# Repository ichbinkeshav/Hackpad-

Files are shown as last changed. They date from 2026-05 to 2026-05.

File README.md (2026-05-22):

# HACKPAD+
Screenshot (93)<br>
This is a hackpad that is based on Xiao Rp2040 that has 9 Buttons and 2 Rotor encoder . I utilized the 2 buttons of rotor encoder as well. So in total i have 11 Keys and 2 rotor encoder. For Keys i used 3 x 4 Matrix so i just need 7 gpio pins for it and 4 gpios for 2 encoder. So the rotor encoder is used to control volume and brightness and the 11 keys are used for general useful shortcuts like copy ,paste ,delete ,screenshot ,open youtube ,cut ,undo ,redo ,print ,window close and open file explore, I did the Schematic and PCB on KICAD and 3d Design on Fusion. The Code is written in circuit Python and uses KMK.I used the hackclub guide , which really helped me a lot.<br>
##  Bill of Materials (BOM)

**#**
1 x XIAO RP2040<br>
**#**
9 x MX-Style switches <br>
**#**
9 x Blank DSA keycaps<br>
**#**
2 x EC11 Rotary Encoder<br>
**#**
4 x  M3x16mm screws <br>
**#**
4 x  M3x5mx4mm heatset inserts

**Schematic**<br><br>
Screenshot (95)<br><br>
**PCB**<br>
Screenshot (96)<br><br>
<br>
**Case**<br><br>
Screenshot (94)
Screenshot (92)

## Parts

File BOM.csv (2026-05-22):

Item | Price | Source
PCB + CASE | 6.43 | JLCPCB
Shipping - Discount JLCPCB | 1.47 | JLCPCB
rotor encoder | 1.84 | https://www.amazon.in/gp/product/B0888RWNM1/ref=ox_sc_act_title_1?smid=A34QREQHZ8C5B0&psc=1
Mx Style switches | 4.29 | https://www.amazon.in/gp/product/B0GCCQLQBV/ref=ox_sc_act_title_3?smid=A16FKXBMFHBYH0&psc=1
KeyCaps | 4.6 | https://www.amazon.in/gp/product/B0F13YK4D6/ref=ox_sc_act_title_2?smid=AH0KEO6T9U8SH&psc=1
XIAO RP2040 | 11.49 | https://www.amazon.in/gp/product/B0FVF1V3P4/ref=ox_sc_act_title_4?smid=AJ6SIZC8YQDZX&psc=1
Heat set and M3 screws | 3.67 | https://www.amazon.in/gp/product/B0DZFPP9SV/ref=ewc_pr_img_1?smid=A350QSP9XUT5HY&psc=1 https://www.amazon.in/gp/product/B07XBSYNQ4/ref=ewc_pr_img_2?smid=AJ6SIZC8YQDZX&th=1
Total | 33.89

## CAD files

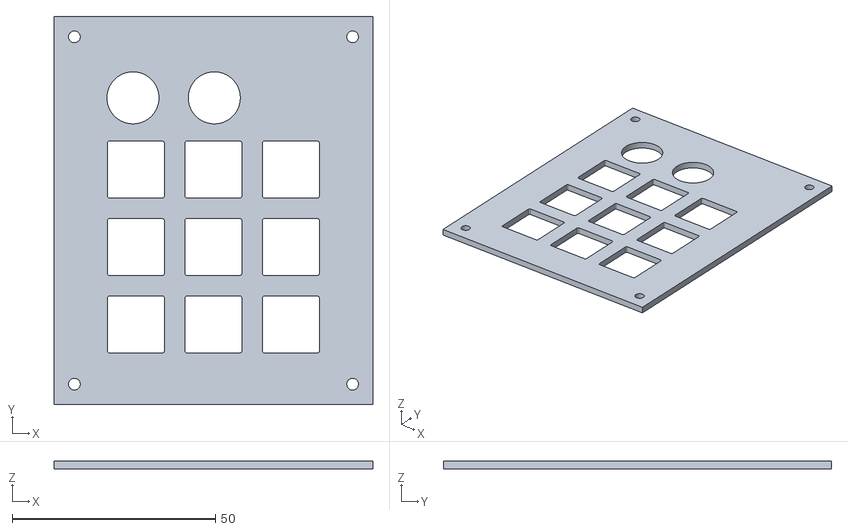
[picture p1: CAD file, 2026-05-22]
HACKPAD+/Production/Top.stl
78.4 x 95.4 x 2.00

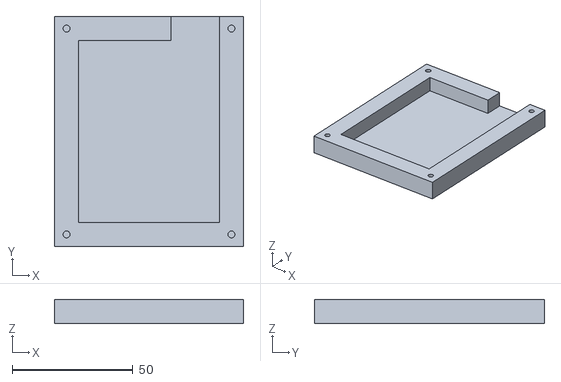
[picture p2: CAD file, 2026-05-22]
HACKPAD+/Production/Base.stl
78.4 x 95.4 x 10.0

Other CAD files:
HACKPAD+/CAD/HACKPAD+.f3d
HACKPAD+/CAD/HACKPAD+.f3z

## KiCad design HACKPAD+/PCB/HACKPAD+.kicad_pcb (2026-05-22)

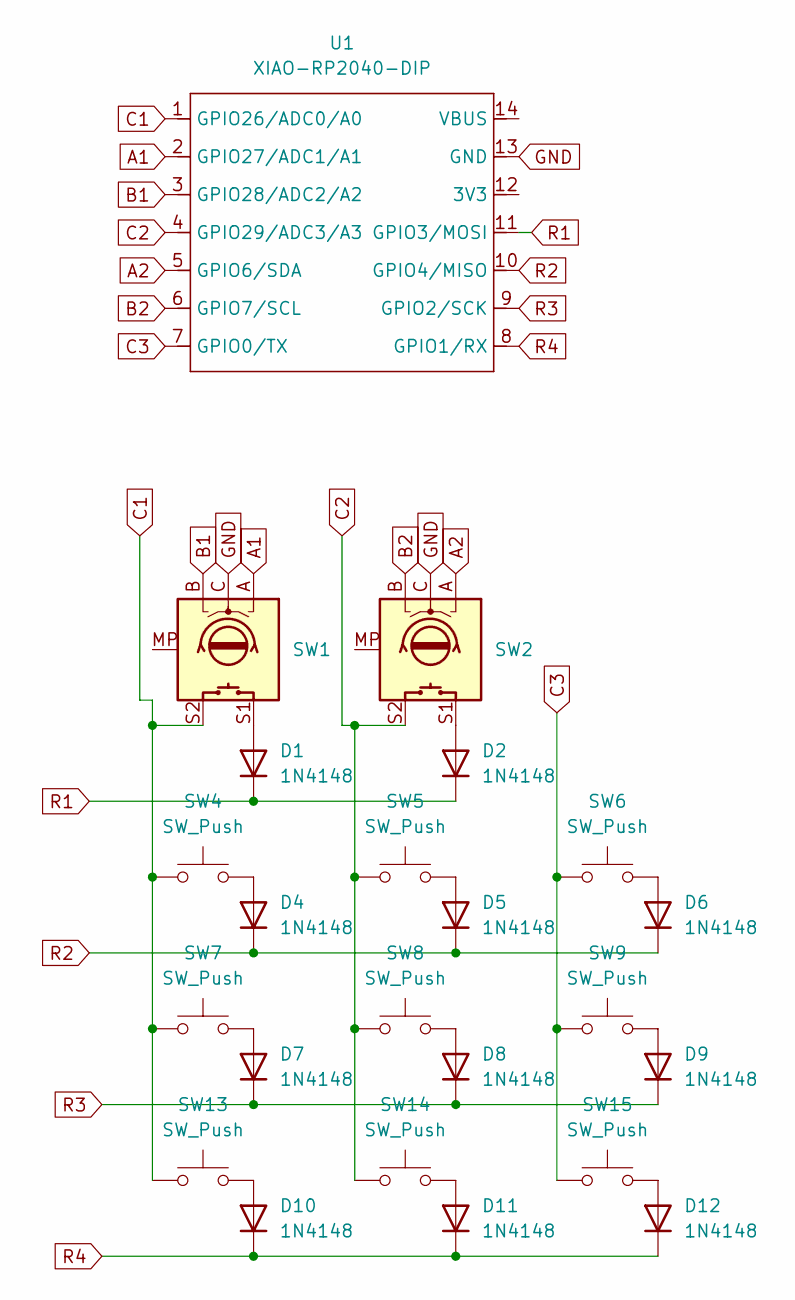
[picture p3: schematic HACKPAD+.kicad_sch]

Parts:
D1, D2, D4, D5, D6, D7, D8, D9, D10, D11, D12: 1N4148; D_DO-35_SOD27_P7.62mm_Horizontal
SW1, SW2: RotaryEncoder_Switch_MP; RotaryEncoder_Alps_EC11E-Switch_Vertical_H20mm
SW4, SW5, SW6, SW7, SW8, SW9, SW13, SW14, SW15: SW_Push; SW_Cherry_MX_1.00u_PCB
U1: XIAO-RP2040-DIP

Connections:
A1: SW1.A, U1.2 (GPIO27/ADC1/A1)
A2: SW2.A, U1.5 (GPIO6/SDA)
B1: SW1.B, U1.3 (GPIO28/ADC2/A2)
B2: SW2.B, U1.6 (GPIO7/SCL)
C1: SW1.S2, SW4.1, SW7.1, SW13.1, U1.1 (GPIO26/ADC0/A0)
C2: SW2.S2, SW5.1, SW8.1, SW14.1, U1.4 (GPIO29/ADC3/A3)
C3: SW6.1, SW9.1, SW15.1, U1.7 (GPIO0/TX)
GND: SW1.C, SW2.C, U1.13 (GND)
unnamed: D1.2 (A), SW1.S1
unnamed: D2.2 (A), SW2.S1
unnamed: D4.2 (A), SW4.2
unnamed: D5.2 (A), SW5.2
unnamed: D6.2 (A), SW6.2
unnamed: D7.2 (A), SW7.2
unnamed: D8.2 (A), SW8.2
unnamed: D9.2 (A), SW9.2
unnamed: D10.2 (A), SW13.2
unnamed: D11.2 (A), SW14.2
unnamed: D12.2 (A), SW15.2
R1: D1.1 (K), D2.1 (K), U1.11 (GPIO3/MOSI)
R2: D4.1 (K), D5.1 (K), D6.1 (K), U1.10 (GPIO4/MISO)
R3: D7.1 (K), D8.1 (K), D9.1 (K), U1.9 (GPIO2/SCK)
R4: D10.1 (K), D11.1 (K), D12.1 (K), U1.8 (GPIO1/RX)

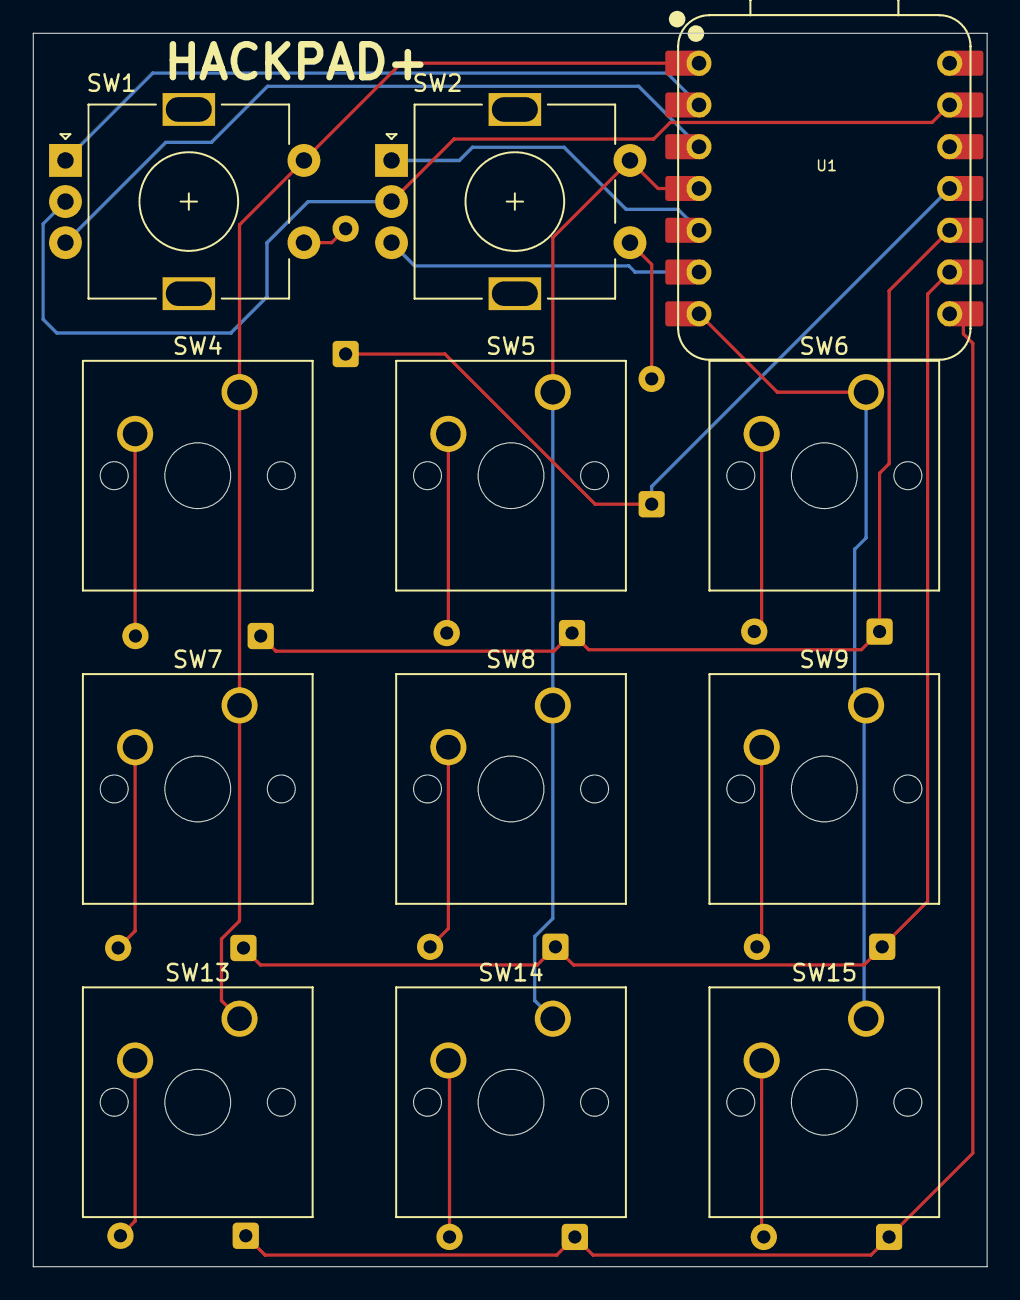
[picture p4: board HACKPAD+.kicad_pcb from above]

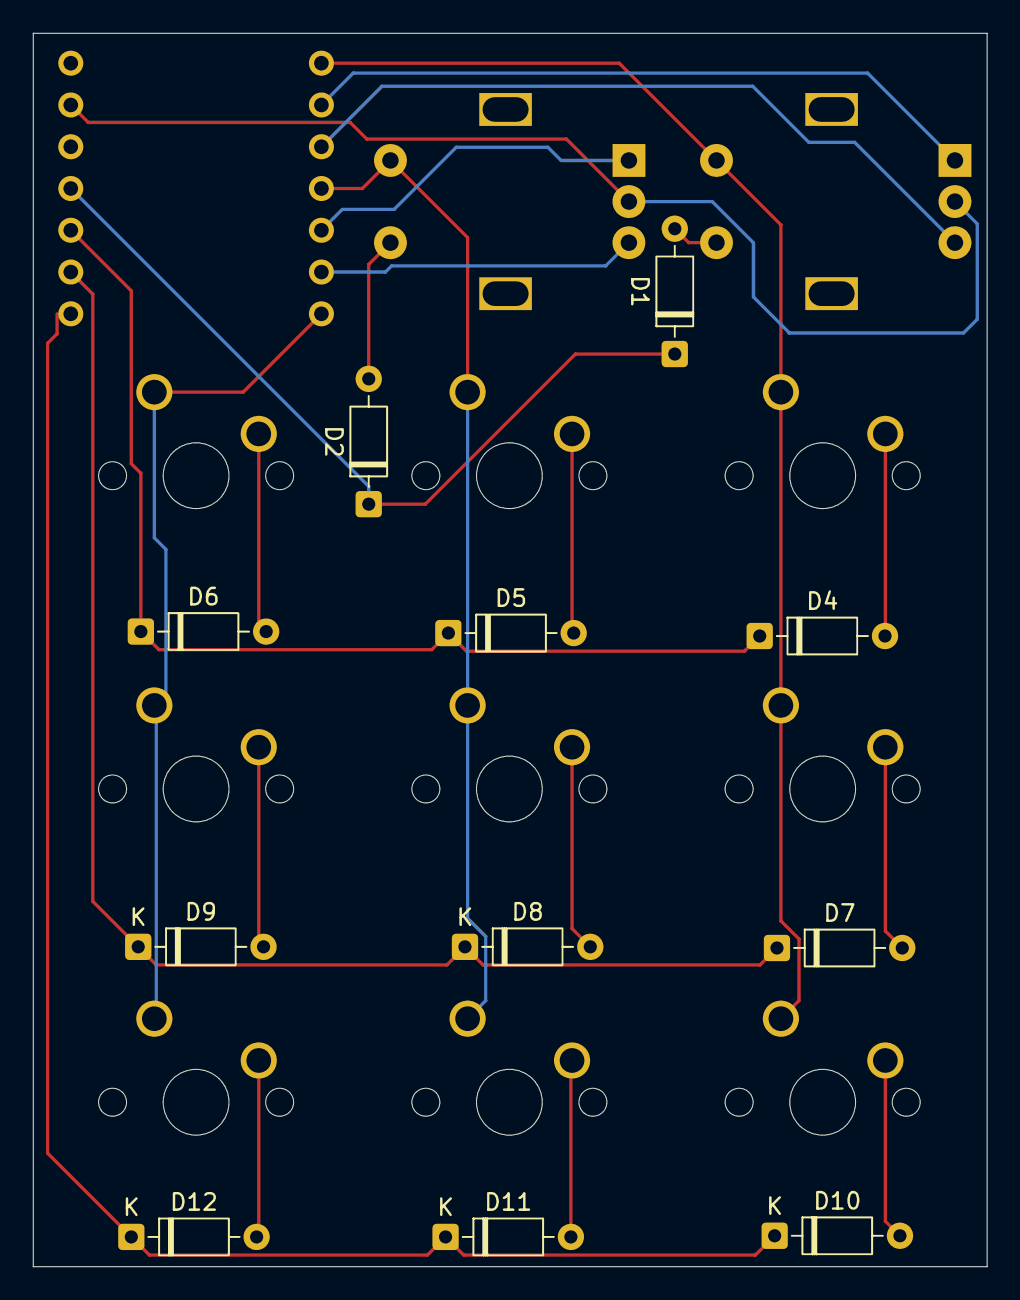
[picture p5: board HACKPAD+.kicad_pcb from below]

Board: 2 copper layers, 58.0 x 75.0 mm, 23 parts (11 on the bottom side), 23 nets.

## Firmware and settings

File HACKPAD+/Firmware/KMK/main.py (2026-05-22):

from kmk.kmk_keyboard import KMKKeyboard
from kmk.keys import KC
from kmk.scanners import DiodeOrientation
from kmk.modules.encoder import EncoderHandler
from kmk.extensions.media_keys import MediaKeys
import board

keyboard = KMKKeyboard()

# ---- MATRIX PINS ----
keyboard.col_pins = (board.GP26, board.GP27, board.GP28)
keyboard.row_pins = (board.GP1, board.GP2, board.GP4, board.GP6)

keyboard.diode_orientation = DiodeOrientation.COL2ROW

# ---- MEDIA EXTENSION ----
keyboard.extensions.append(MediaKeys())

# ---- ENCODERS ----
encoder_handler = EncoderHandler()
keyboard.modules.append(encoder_handler)

# Encoder 1 → Volume
# Encoder 2 → Brightness
encoder_handler.pins = (
    ((board.GP7, board.GP0, None),),   # Encoder 1
    ((board.GP29, board.GP3, None),),  # Encoder 2
)

encoder_handler.map = [
    ((KC.VOLD, KC.VOLU),),   # Encoder 1
    ((KC.BRIGHTNESS_DOWN, KC.BRIGHTNESS_UP),),  # Encoder 2
]

# ---- MACROS ----
YOUTUBE = KC.LGUI(KC.R)  # Windows+R
SCREENSHOT = KC.LGUI(KC.PRINT_SCREEN)

keyboard.keymap = [
    [
        KC.LCTL(KC.C),      # Copy
        KC.LCTL(KC.V),      # Paste
        KC.DELETE,          # Delete

        SCREENSHOT,         # Screenshot
        KC.PRINT_SCREEN,    # Print Screen
        YOUTUBE,            # Open Run (type youtube.com)

        KC.LCTL(KC.X),      # Cut
        KC.LCTL(KC.Z),      # Undo
        KC.LCTL(KC.Y),      # Redo

        KC.LGUI(KC.E),      # File Explorer
        KC.LALT(KC.F4),     # Close Window
        KC.NO               # extra slot
    ]
]

if __name__ == '__main__':
    keyboard.go()

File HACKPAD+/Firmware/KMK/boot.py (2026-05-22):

import board
import digitalio
import storage
import usb_cdc
import usb_hid
import time

# ---- MATRIX PINS ----
cols = [board.GP26, board.GP27, board.GP28]  # C1 C2 C3
rows = [board.GP1, board.GP2, board.GP4, board.GP6]  # R1 R2 R3 R4

# Setup columns as input pullups
col_ios = []
for pin in cols:
    col = digitalio.DigitalInOut(pin)
    col.direction = digitalio.Direction.INPUT
    col.pull = digitalio.Pull.UP
    col_ios.append(col)

# Setup rows as output low
row_ios = []
for pin in rows:
    row = digitalio.DigitalInOut(pin)
    row.direction = digitalio.Direction.OUTPUT
    row.value = False
    row_ios.append(row)

time.sleep(0.1)

key_pressed = False

# Scan matrix once
for row in row_ios:
    row.value = False
    for col in col_ios:
        if not col.value:  # Active LOW
            key_pressed = True
    row.value = True

if key_pressed:
    # SAFE MODE (no keyboard)
    storage.enable_usb_drive()
    usb_hid.disable()
else:
    # Normal keyboard mode
    storage.disable_usb_drive()
